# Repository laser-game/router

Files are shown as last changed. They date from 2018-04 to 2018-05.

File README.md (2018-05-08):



# Router
Devices for route wireless communication between the control computer and laser game devices.

placement

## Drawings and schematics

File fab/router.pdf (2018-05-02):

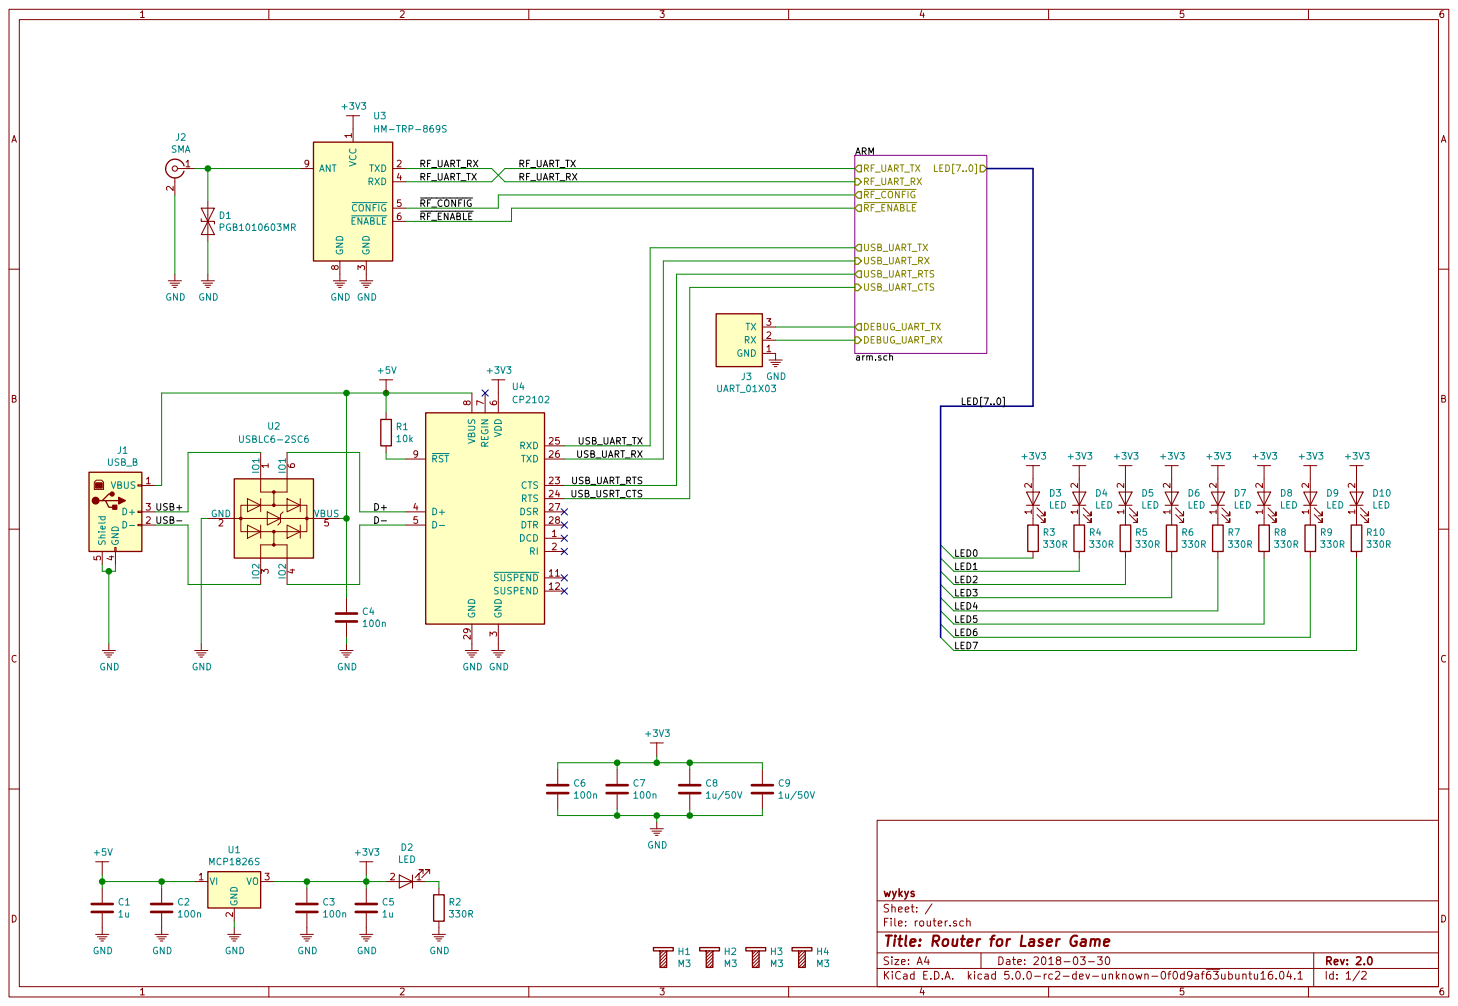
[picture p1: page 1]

3 RXD 4 CONFIG 5 ENABLE 6 GND

8 RST 9 GND 29 U4CP2102 USB+ USB- D+D- R1

Id: 1/2 Title: Router for Laser Game

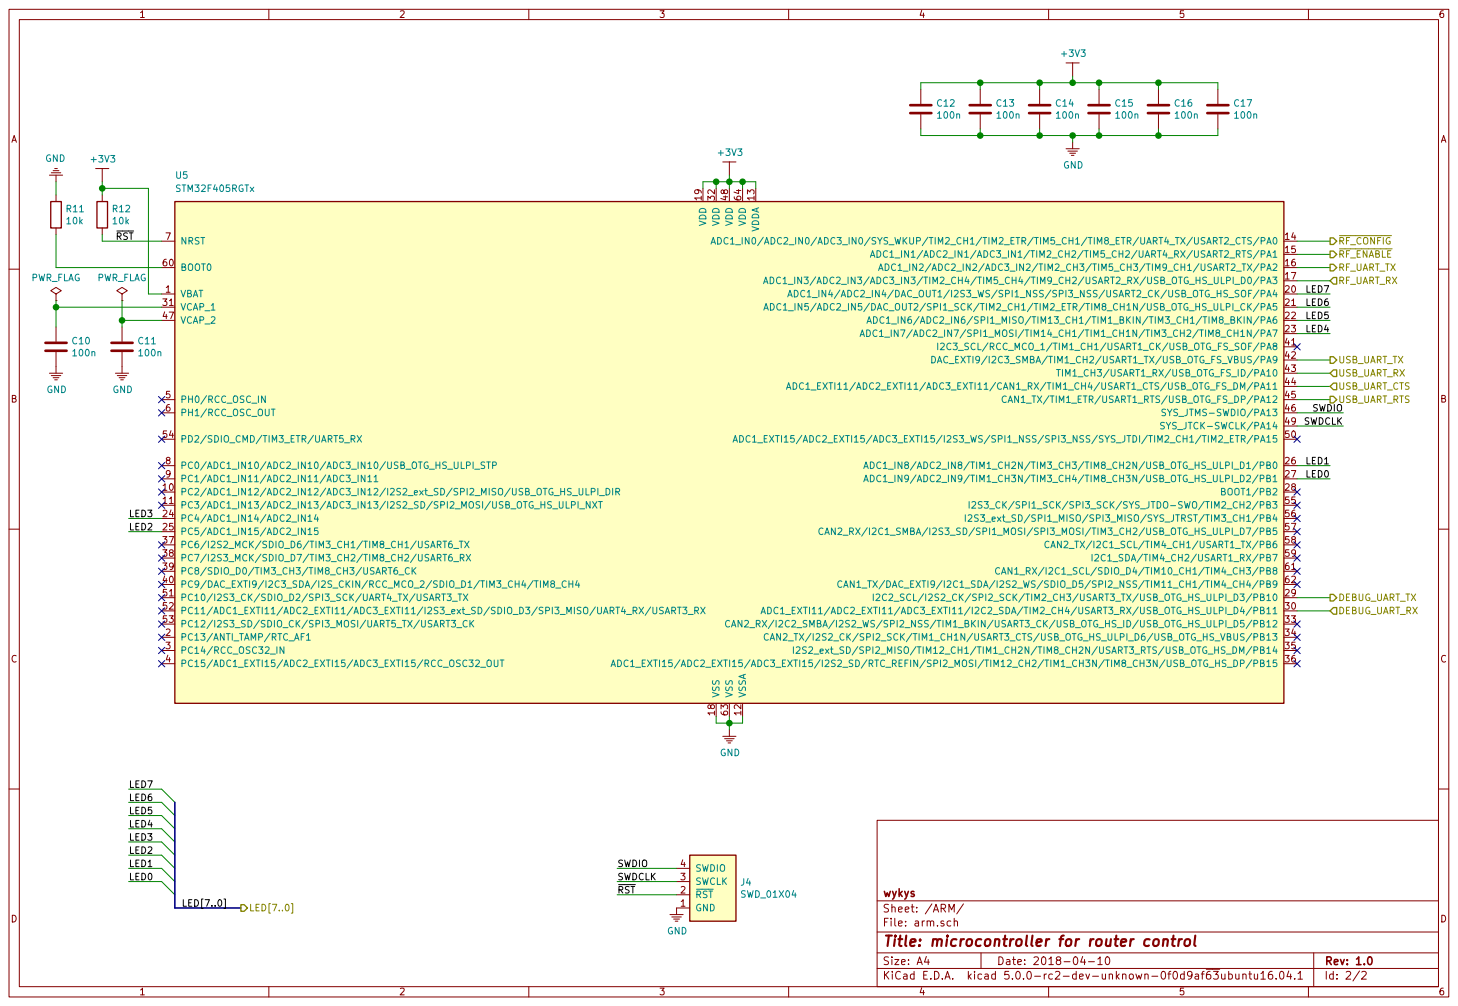
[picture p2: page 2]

Id: 2/2 Title: microcontroller for router control File: arm.sch Sheet: /ARM/ wykys

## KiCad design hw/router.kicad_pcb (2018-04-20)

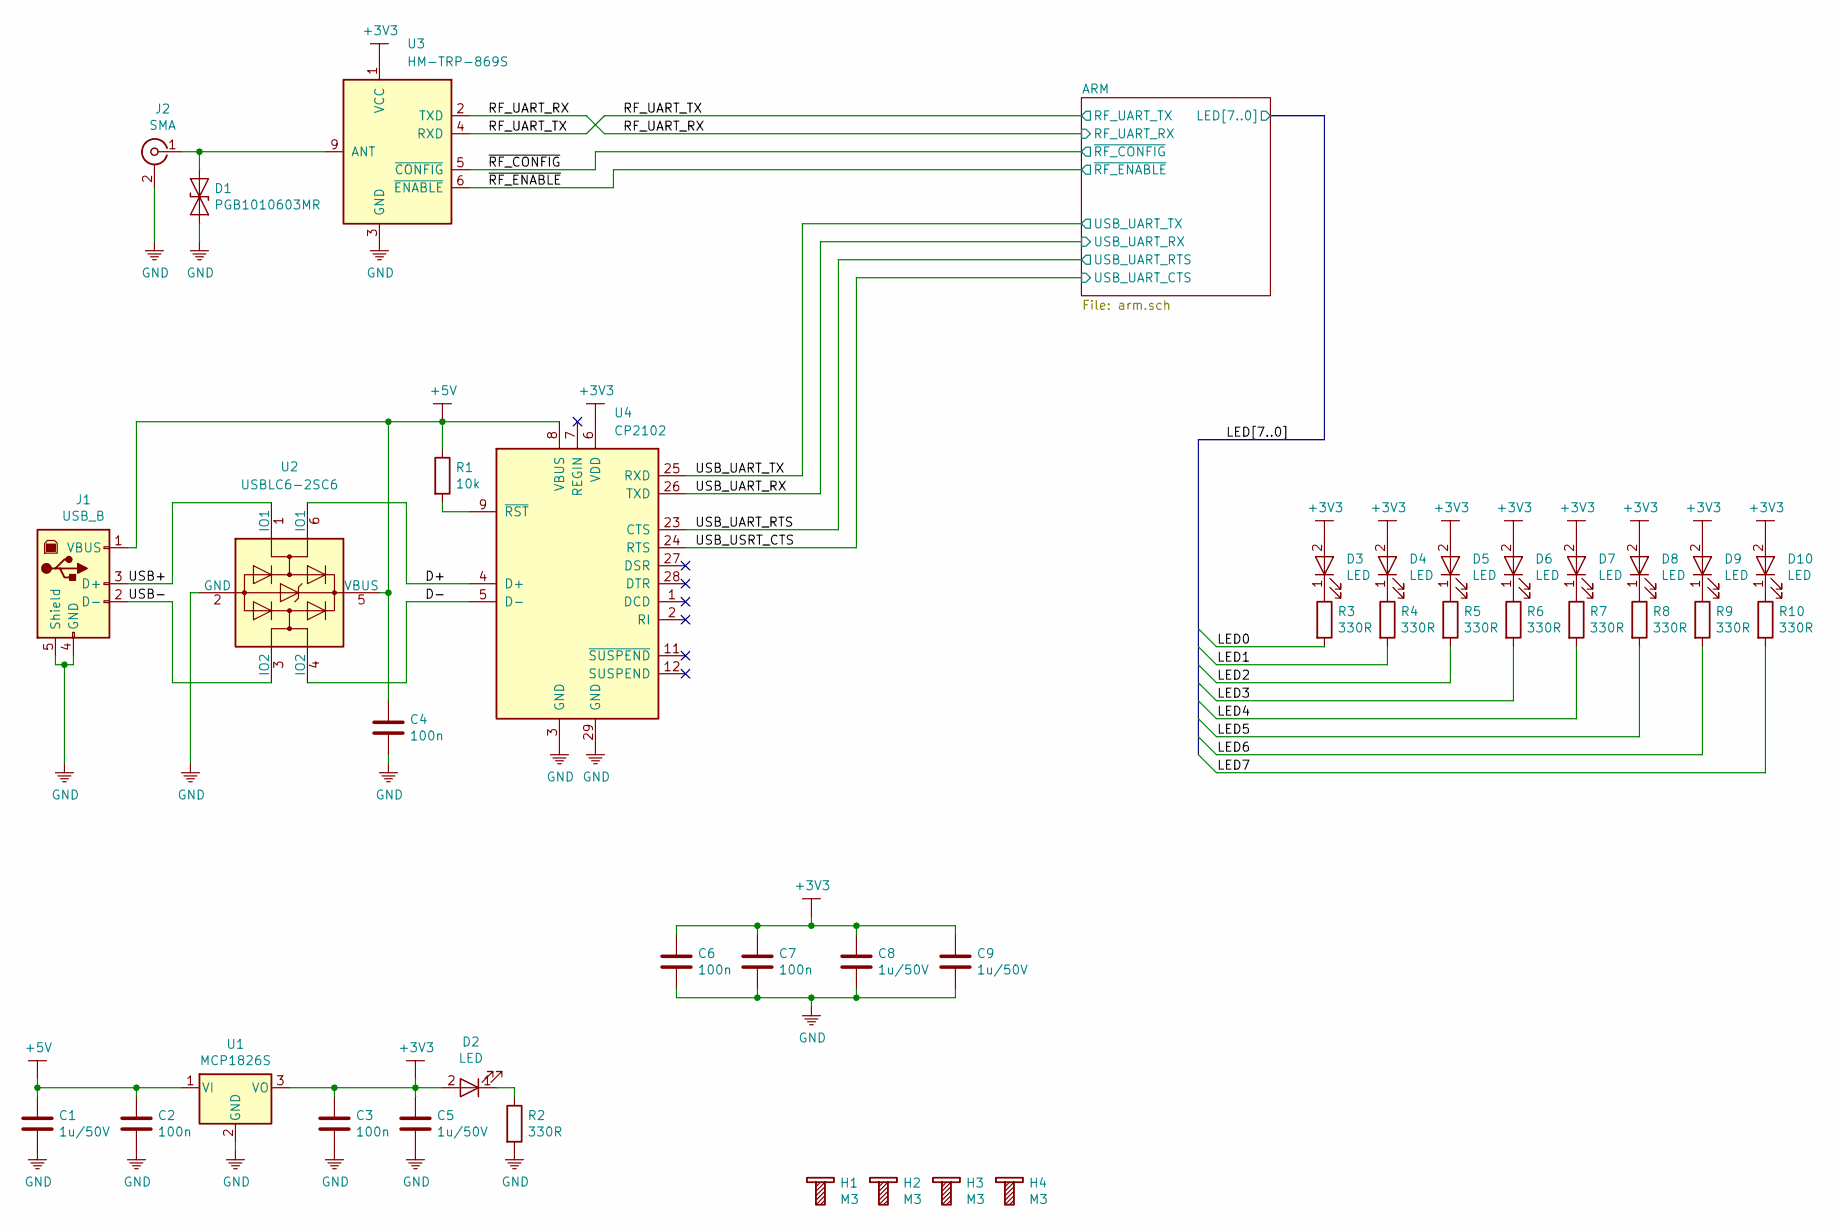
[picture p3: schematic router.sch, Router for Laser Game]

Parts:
C1, C5, C8, C9: 1u/50V; C_0805_2012Metric
C2, C3, C4, C6, C7: 100n; C_0805_2012Metric
D1: PGB1010603MR; D_0603_1608Metric
D2, D3, D4, D5, D6, D7, D8, D9, D10: LED; LED_0805_2012Metric
H1, H2, H3, H4: M3; Bolt_M3
J1: USB_B; USB_B_TE_5787834_Vertical
J2: SMA; SMA_Jack_Vertical
R1: 10k; R_0805_2012Metric
R2, R3, R4, R5, R6, R7, R8, R9, R10: 330R; R_0805_2012Metric
U1: MCP1826S; SOT-223-3_TabPin2
U2: USBLC6-2SC6; SOT-23-6
U3: HM-TRP-869S; HM-TRP-SMD
U4: CP2102; QFN-28-1EP_5x5mm_P0.5mm_EP3.35x3.35mm

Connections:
+3V3: C3.1, C5.1, C6.1, C7.1, C8.1, C9.1, D2.2 (A), D3.2 (A), D4.2 (A), D5.2 (A), D6.2 (A), D7.2 (A), D8.2 (A), D9.2 (A), D10.2 (A), U1.3 (VO), U3.1 (VCC), U4.6 (VDD); also elsewhere on the board
+5V: C1.1, C2.1, C4.1, J1.1 (VBUS), R1.1, U1.1 (VI), U2.5 (VBUS), U4.8 (VBUS)
/D+: U2.6 (IO1), U4.4 (D+)
/D-: U2.4 (IO2), U4.5 (D-)
/LED0: R3.2; also elsewhere on the board
/LED1: R4.2; also elsewhere on the board
/LED2: R5.2; also elsewhere on the board
/LED3: R6.2; also elsewhere on the board
/LED4: R7.2; also elsewhere on the board
/LED5: R8.2; also elsewhere on the board
/LED6: R9.2; also elsewhere on the board
/LED7: R10.2; also elsewhere on the board
/RF_UART_RX: U3.2 (TXD); also elsewhere on the board
/RF_UART_TX: U3.4 (RXD); also elsewhere on the board
/USB+: J1.3 (D+), U2.1 (IO1)
/USB-: J1.2 (D-), U2.3 (IO2)
/USB_UART_RTS: U4.23 (CTS); also elsewhere on the board
/USB_UART_RX: U4.26 (TXD); also elsewhere on the board
/USB_UART_TX: U4.25 (RXD); also elsewhere on the board
/USB_USRT_CTS: U4.24 (RTS); also elsewhere on the board
/~RF_CONFIG: U3.5 (~CONFIG); also elsewhere on the board
/~RF_ENABLE: U3.6 (~ENABLE); also elsewhere on the board
GND: C1.2, C2.2, C3.2, C4.2, C5.2, C6.2, C7.2, C8.2, C9.2, D1.2 (A2), J1.4 (GND), J1.5 (Shield), J2.2 (Ext), R2.2, U1.2 (GND), U2.2 (GND), U3.3 (GND), U3.8 (GND), U4.3 (GND), U4.29 (GND); also elsewhere on the board
unnamed: D1.1 (A1), J2.1 (In), U3.9 (ANT)
unnamed: D2.1 (K), R2.1
unnamed: D3.1 (K), R3.1
unnamed: D4.1 (K), R4.1
unnamed: D5.1 (K), R5.1
unnamed: D6.1 (K), R6.1
unnamed: D7.1 (K), R7.1
unnamed: D8.1 (K), R8.1
unnamed: D9.1 (K), R9.1
unnamed: D10.1 (K), R10.1
unnamed: R1.2, U4.9 (~RST)

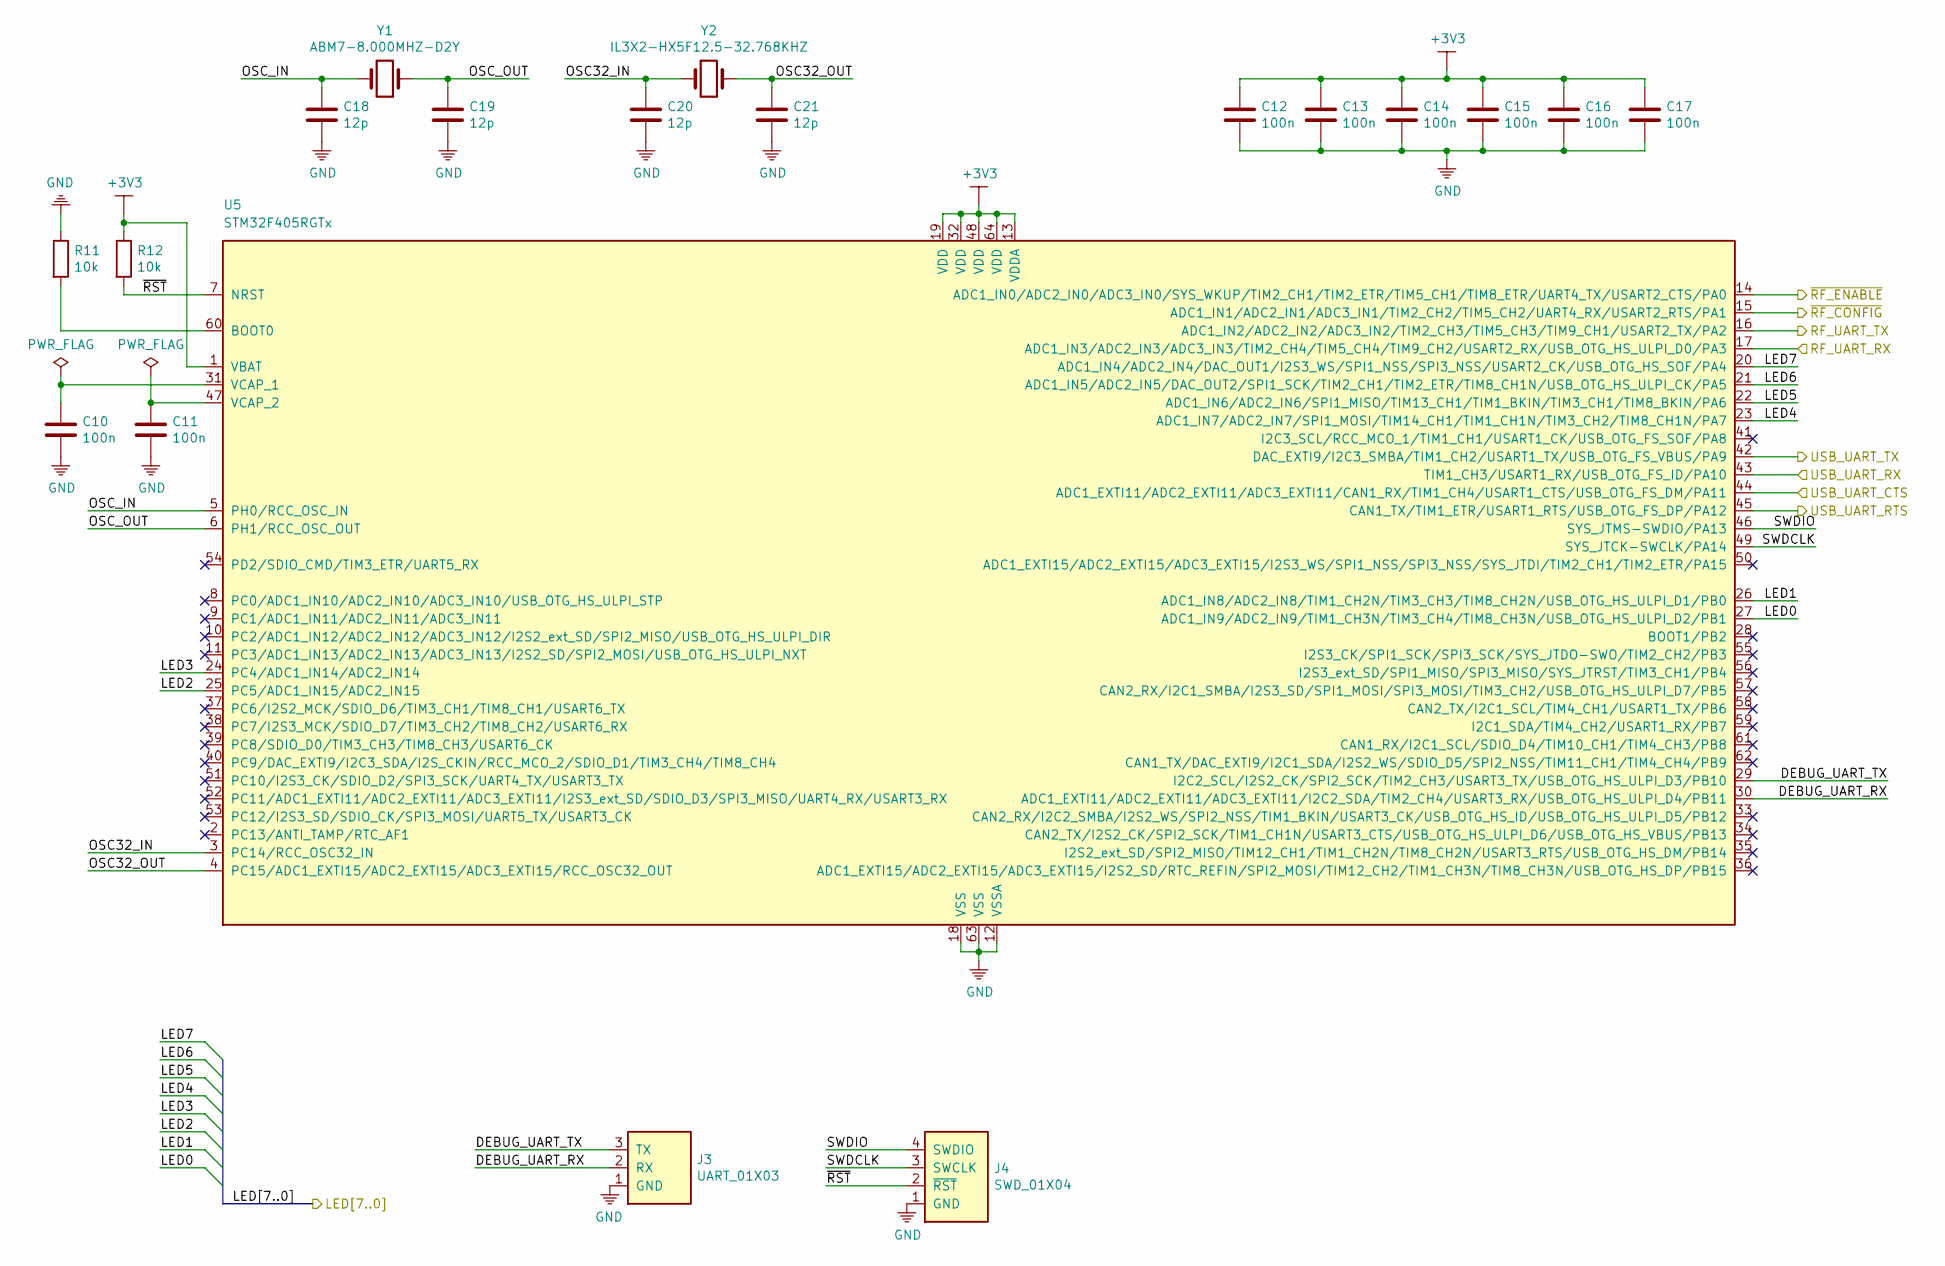
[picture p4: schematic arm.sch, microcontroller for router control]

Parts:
C10, C11, C12, C13, C14, C15, C16, C17: 100n; C_0805_2012Metric
C18, C19, C20, C21: 12p; C_0805_2012Metric
J3: UART_01X03; PinHeader_1x03_P2.54mm_Vertical
J4: SWD_01X04; PinHeader_1x04_P2.54mm_Vertical
R11, R12: 10k; R_0805_2012Metric
U5: STM32F405RGTx; TQFP-64_10x10mm_P0.5mm
Y1: ABM7-8.000MHZ-D2Y; Crystal_SMD_2012-2Pin_2.0x1.2mm_HandSoldering
Y2: IL3X2-HX5F12.5-32.768KHZ; Crystal_SMD_2012-2Pin_2.0x1.2mm_HandSoldering

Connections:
+3V3: C12.1, C13.1, C14.1, C15.1, C16.1, C17.1, R12.1, U5.1 (VBAT), U5.13 (VDDA), U5.19 (VDD), U5.32 (VDD), U5.48 (VDD), U5.64 (VDD); also elsewhere on the board
/ARM/DEBUG_UART_RX: J3.2 (RX), U5.30 (ADC1_EXTI11/ADC2_EXTI11/ADC3_EXTI11/I2C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)
/ARM/DEBUG_UART_TX: J3.3 (TX), U5.29 (I2C2_SCL/I2S2_CK/SPI2_SCK/TIM2_CH3/USAR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)
/ARM/OSC32_IN: C20.1, U5.3 (PC14/RCC_OSC32_IN), Y2.1
/ARM/OSC32_OUT: C21.1, U5.4 (PC15/ADC1_EXTI15/ADC2_EXTI15/ADC3_EXTI1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), Y2.2
/ARM/OSC_IN: C18.1, U5.5 (PH0/RCC_OSC_IN), Y1.1
/ARM/OSC_OUT: C19.1, U5.6 (PH1/RCC_OSC_OUT), Y1.2
/ARM/SWDCLK: J4.3 (SWCLK), U5.49 (SYS_JTCK-SWCLK/PA14)
/ARM/SWDIO: J4.4 (SWDIO), U5.46 (SYS_JTMS-SWDIO/PA13)
/ARM/~RST: J4.2 (~RST), R12.2, U5.7 (NRST)
/LED0: U5.27 (ADC1_IN9/ADC2_IN9/TIM1_CH3N/TIM3_CH4/TI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); also elsewhere on the board
/LED1: U5.26 (ADC1_IN8/ADC2_IN8/TIM1_CH2N/TIM3_CH3/TI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); also elsewhere on the board
/LED2: U5.25 (PC5/ADC1_IN15/ADC2_IN15); also elsewhere on the board
/LED3: U5.24 (PC4/ADC1_IN14/ADC2_IN14); also elsewhere on the board
/LED4: U5.23 (ADC1_IN7/ADC2_IN7/SPI1_MOSI/TIM14_CH1/T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); also elsewhere on the board
/LED5: U5.22 (ADC1_IN6/ADC2_IN6/SPI1_MISO/TIM13_CH1/T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); also elsewhere on the board
/LED6: U5.21 (ADC1_IN5/ADC2_IN5/DAC_OUT2/SPI1_SCK/TIM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); also elsewhere on the board
/LED7: U5.20 (ADC1_IN4/ADC2_IN4/DAC_OUT1/I2S3_WS/SPI1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); also elsewhere on the board
/RF_UART_RX: U5.17 (ADC1_IN3/ADC2_IN3/ADC3_IN3/TIM2_CH4/TIM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); also elsewhere on the board
/RF_UART_TX: U5.16 (ADC1_IN2/ADC2_IN2/ADC3_IN2/TIM2_CH3/TIM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); also elsewhere on the board
/USB_UART_RTS: U5.45 (CAN1_TX/TIM1_ETR/USART1_RTS/USB_OTG_FS_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); also elsewhere on the board
/USB_UART_RX: U5.43 (TIM1_CH3/USART1_RX/USB_OTG_FS_ID/PA10); also elsewhere on the board
/USB_UART_TX: U5.42 (DAC_EXTI9/I2C3_SMBA/TIM1_CH2/USART1_TX/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); also elsewhere on the board
/USB_USRT_CTS: U5.44 (ADC1_EXTI11/ADC2_EXTI11/ADC3_EXTI11/CAN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); also elsewhere on the board
/~RF_CONFIG: U5.15 (ADC1_IN1/ADC2_IN1/ADC3_IN1/TIM2_CH2/TIM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); also elsewhere on the board
/~RF_ENABLE: U5.14 (ADC1_IN0/ADC2_IN0/ADC3_IN0/SYS_WKUP/TIM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); also elsewhere on the board
GND: C10.2, C11.2, C12.2, C13.2, C14.2, C15.2, C16.2, C17.2, C18.2, C19.2, C20.2, C21.2, J3.1 (GND), J4.1 (GND), R11.1, U5.12 (VSSA), U5.18 (VSS), U5.63 (VSS); also elsewhere on the board
unnamed: C10.1, U5.31 (VCAP_1)
unnamed: C11.1, U5.47 (VCAP_2)
unnamed: R11.2, U5.60 (BOOT0)

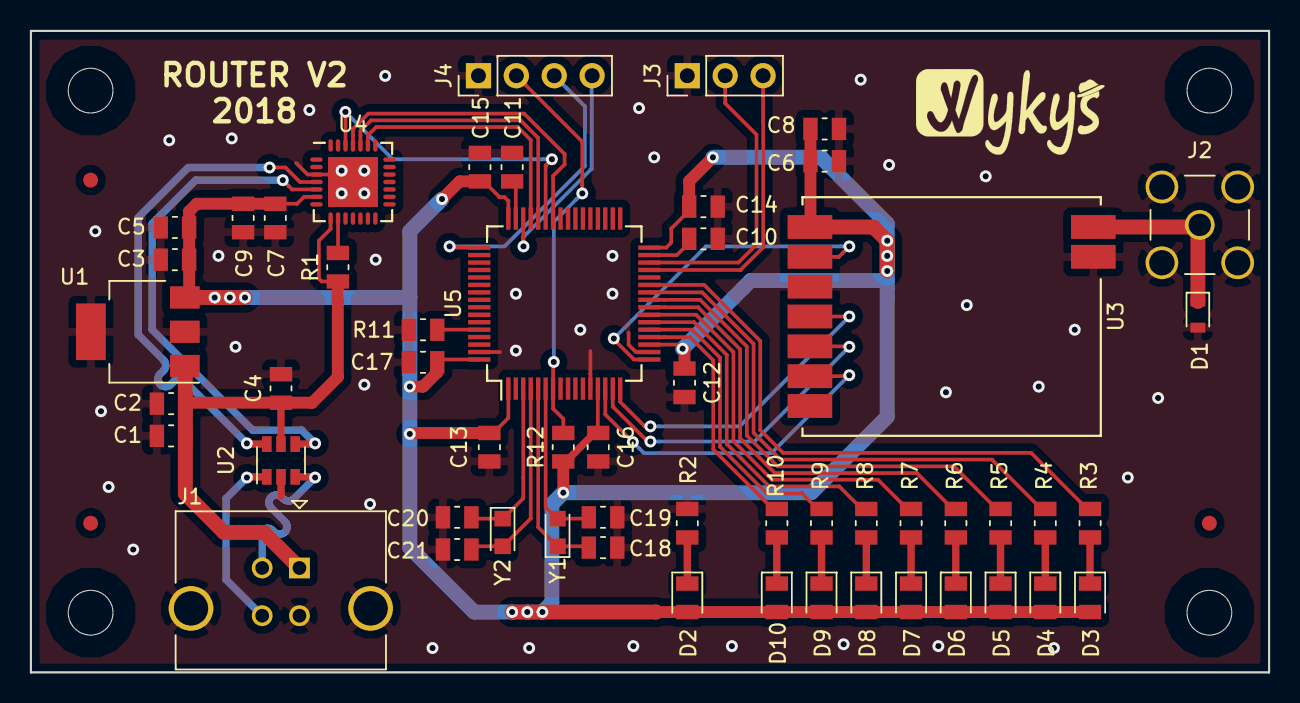
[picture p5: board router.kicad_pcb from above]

Board: 2 copper layers, 83.0 x 43.0 mm, 58 parts (0 on the bottom side), 46 nets.

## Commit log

2018-03-30 created schematic
    [router.kicad_pcb, router.sch]
2018-04-10 changed mcu from STM32F401CEUx to STM32F405RGTx and split schematic to more sheets
    [arm.sch, router.sch]
2018-04-13 updated schematic
    [arm.sch, router.sch]
2018-04-14 created pcb
    [arm.sch, router.kicad_pcb]
2018-04-15 added meanders
    [router.kicad_pcb]
2018-04-20 added fiducials
    [router.kicad_pcb]
2018-04-20 updated USB footprint
    [router.kicad_pcb]
2018-05-02 added boom file and schematic for fabracation
    [router.csv]
2018-05-06 added placement file
    [router.sch]

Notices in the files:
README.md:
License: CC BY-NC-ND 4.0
